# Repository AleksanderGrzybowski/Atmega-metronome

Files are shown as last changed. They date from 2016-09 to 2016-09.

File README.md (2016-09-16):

This is ATmega8 based metronome, useful for my guitar practice. I needed something with wider range of BPM-s, cause my other device only goes down to 40 BPM. Sound is produced from typical 8 Ohm speaker. Board was produced in Merkar (Katowice).
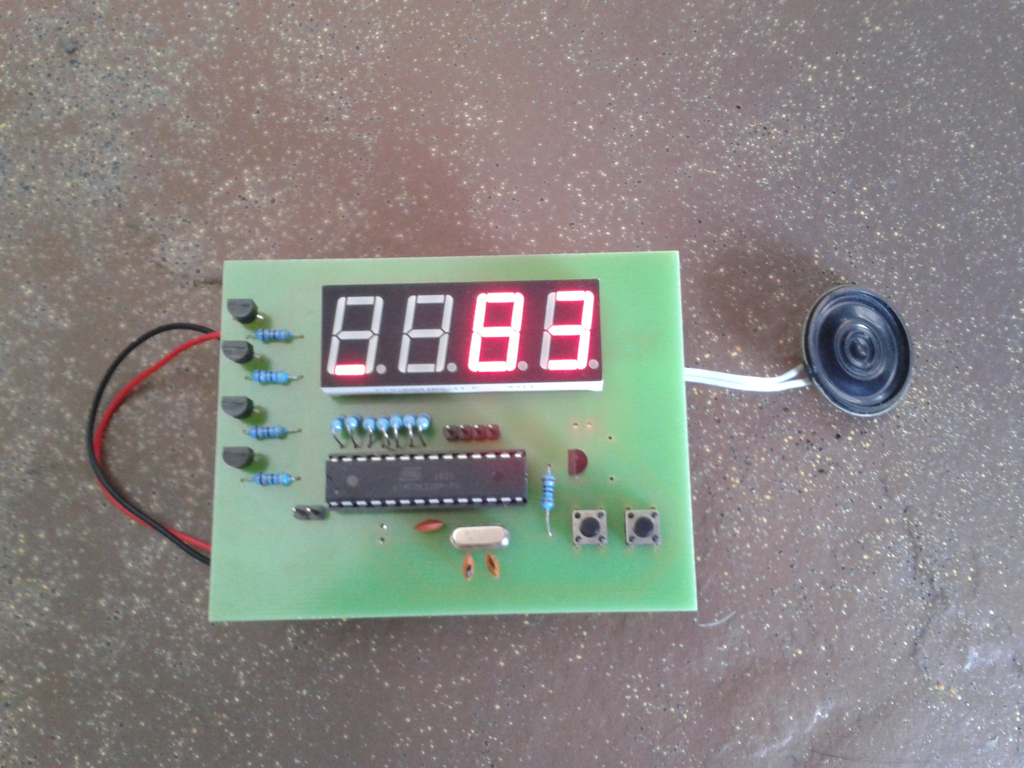
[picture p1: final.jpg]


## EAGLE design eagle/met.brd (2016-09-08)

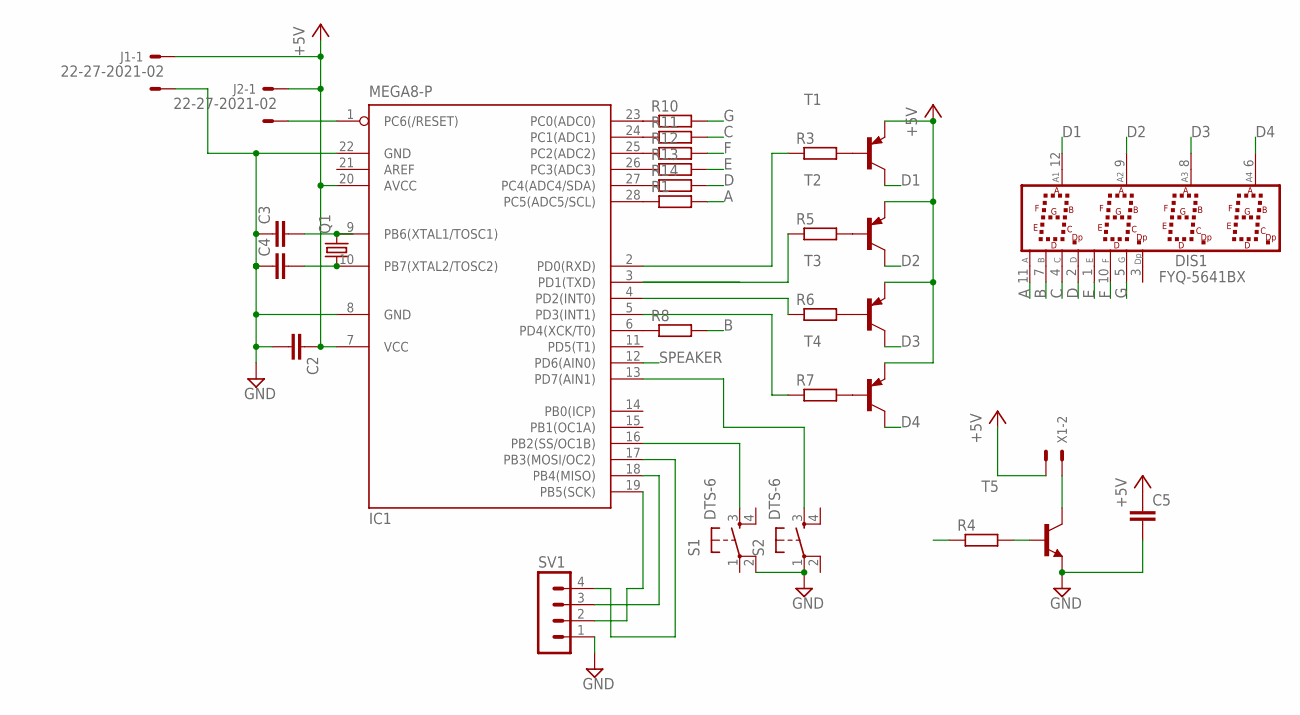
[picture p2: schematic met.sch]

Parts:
C2, C3, C4: C-EU025-024X044; C025-024X044
C5: C-EU075-032X103; C075-032X103
DIS1: FYQ-5641BX; FYQ5641
IC1: MEGA8-P; DIL28-3
J1, J2: 22-27-2021-02; 6410-02
Q1: CRYSTALS-NOGND-HC49; HC49
R1, R8, R10, R11, R12, R13, R14: R-EU_0204/5; 0204/5
R3, R5, R6, R7: R-EU_0207/10; 0207/10
R4: R-EU_0309/12; 0309/12
S1, S2: DTS-6
SV1: MA04-1
T1, T2, T3, T4: BC327-PNP-TO92-EBC; TO92-EBC
T5: BC337-40-NPN-TO92-CBE; TO92-CBE
X1: 22-23-2021

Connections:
+5V: C2.1, C5.1, IC1.7 (VCC), IC1.20 (AVCC), J1.1, T1.E, T2.E, T3.E, T4.E, X1.1
A: DIS1.11 (A), R1.2
B: DIS1.7 (B), R8.2
C: DIS1.4 (C), R11.2
D: DIS1.2 (D), R14.2
D1: DIS1.12 (A1), T1.C
D2: DIS1.9 (A2), T2.C
D3: DIS1.8 (A3), T3.C
D4: DIS1.6 (A4), T4.C
E: DIS1.1 (E), R13.2
F: DIS1.10 (F), R12.2
G: DIS1.5 (G), R10.2
GND: C2.2, C3.1, C4.1, C5.2, IC1.8 (GND), IC1.22 (GND), J1.2, S1.2, S2.1, SV1.1, T5.E
unnamed: C3.2, IC1.9 (PB6(XTAL1/TOSC1)), Q1.2
unnamed: C4.2, IC1.10 (PB7(XTAL2/TOSC2)), Q1.1
unnamed: R3.2, T1.B
unnamed: IC1.1 (PC6(/RESET)), J2.2
unnamed: R5.2, T2.B
unnamed: R6.2, T3.B
unnamed: R7.2, T4.B
unnamed: IC1.2 (PD0(RXD)), R3.1
unnamed: IC1.3 (PD1(TXD)), R5.1
unnamed: IC1.4 (PD2(INT0)), R6.1
unnamed: IC1.5 (PD3(INT1)), R7.1
unnamed: IC1.16 (PB2(SS/OC1B)), S1.3
unnamed: IC1.13 (PD7(AIN1)), S2.3
unnamed: IC1.6 (PD4(XCK/T0)), R8.1
unnamed: IC1.23 (PC0(ADC0)), R10.1
unnamed: IC1.24 (PC1(ADC1)), R11.1
unnamed: IC1.25 (PC2(ADC2)), R12.1
unnamed: IC1.26 (PC3(ADC3)), R13.1
unnamed: IC1.27 (PC4(ADC4/SDA)), R14.1
unnamed: IC1.28 (PC5(ADC5/SCL)), R1.1
unnamed: T5.C, X1.2
unnamed: IC1.19 (PB5(SCK)), SV1.2
unnamed: IC1.18 (PB4(MISO)), SV1.3
unnamed: IC1.17 (PB3(MOSI/OC2)), SV1.4
OFDS: R4.2, T5.B
SPEAKER: IC1.12 (PD6(AIN0)), R4.1

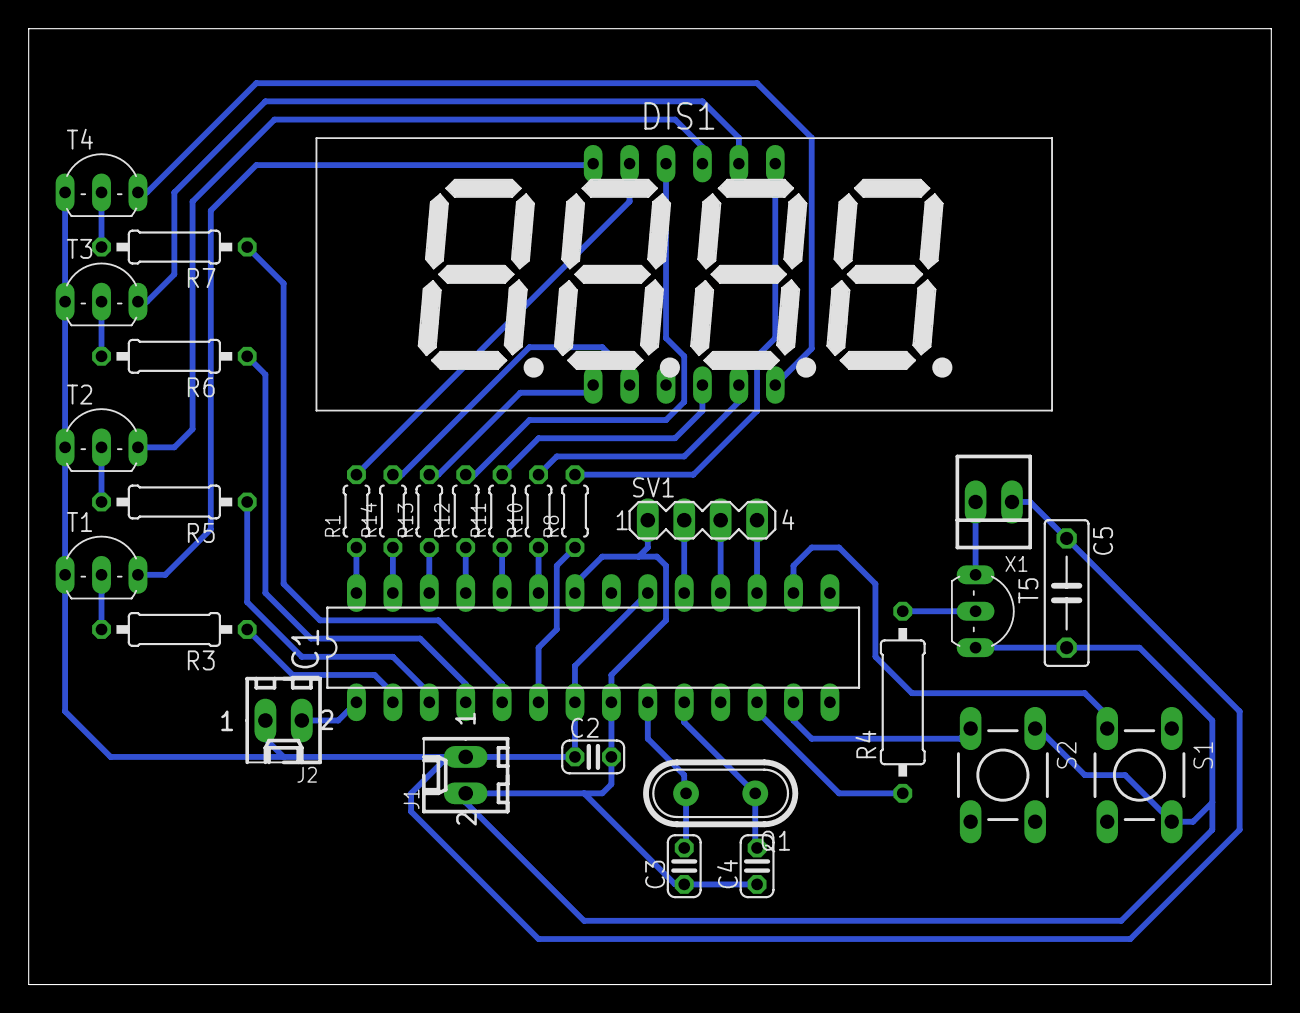
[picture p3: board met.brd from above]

Board: 2 copper layers, 86.7 x 66.7 mm, 30 parts (0 on the bottom side), 39 nets.

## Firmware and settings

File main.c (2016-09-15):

#include <avr/io.h>
#include <util/delay.h>
#include <avr/interrupt.h>
#include <avr/sleep.h>
#include <stdbool.h>

#include "bpm_table.h"

#define B 64
#define A 32
#define D 16
#define E 8
#define F 4
#define C 2
#define G 1


uint8_t digits[12] = { 
    (A + B + C + D + E + F),
    (B + C),
    (A + B + G + E + D),
    (A + B + G + C + D),
    (F + G + B + C),
    (A + F + G + C + D),
    (A + F + G + E + D + C),
    (F + A + B + C),
    (A + B + C + D + E + F + G),
    (A + B + C + D + F + G),
    (0),
    (G)
};

#define EMPTY_DIGIT 10

uint8_t display[4];

void setup_interrupts() {
    // timer 1
    TCCR1B &= ~(1 << CS11);
    TCCR1B |= (1 << CS10) | (1 << CS12);
    TIMSK1 |= (1 << TOIE1);
    TCNT1 = 65530; // some high-ish value
    
    // timer 0
    TCCR0A |= (1 << COM0A1) | (1 << COM0A0) | (1 << WGM00);
    TCCR0B |= (1 << CS00);
    TIMSK0 |= (1 << TOIE0);
    OCR0A = 255; // turned off

    sei();
}


void setup() {
    setup_interrupts();
}

// There was some strange transient that caused a need for this on breadboard,
// not sure if needed now
uint16_t current_bpm = 60 + 1;

bool buzzing = false;
uint8_t buzzing_counter = 0;
#define SOUND_DURATION 10
#define SOUND_PWM_VALUE 128

uint8_t current_digit = 0;


ISR(TIMER0_OVF_vect) {
    if (++current_digit == 4) current_digit = 0;

    // turn off pnp-s to avoid ghosting
    PORTD |= 0b00001111;

    PORTC |= 0b00111111;
    PORTC &= ~(display[current_digit] & 0b00111111);

    // One LCD segment is on PORTD (board routing limitations), so 6-th bit is
    // used for it
    if (display[current_digit] & 0b01000000) { 
        PORTD &= ~(1 << PD4);
    } else {
        PORTD |= (1 << PD4);
    }

    PORTD &= ~(1 << current_digit);

    if (buzzing) {
        OCR0A = SOUND_PWM_VALUE;
        buzzing_counter++;
        if (buzzing_counter > SOUND_DURATION) {
            OCR0A = 255;
            buzzing = false;
            buzzing_counter = 0;
        }
    }
}


uint8_t animation_tab[] = {A, G, D, G}; // top, center, bottom, center, ...
uint8_t animation_index = 0;

ISR(TIMER1_OVF_vect) {
    // array is indexed from 0, so shifting here
    TCNT1 = 65536 - bpm[current_bpm-20];
    buzzing = 1;

    animation_index++;
    if (animation_index >= sizeof(animation_tab)/sizeof(uint8_t)) animation_index = 0;
    display[0] = animation_tab[animation_index];
}

void display_number(uint16_t number) { // 3-digit, first digit is used for animation
    int tmp[3];
    tmp[0] = number % 10;
    number /= 10;
    tmp[1] = number % 10;
    number /= 10;
    tmp[2] = number % 10;

    // remove leading zeros
    int i = 2;
    for (i = 2; i > 0; --i) {
        if (tmp[i] == 0) tmp[i] = EMPTY_DIGIT;
        else break;
    }

    display[1] = digits[tmp[2]];
    display[2] = digits[tmp[1]];
    display[3] = digits[tmp[0]];
}

#define MAX_BPM 200
#define MIN_BPM 20

int main(void) {
    setup();

    DDRC = 0b00111111;
    DDRD = 0b01011111;
    DDRB = 0b00000011;

    // buttons
    PORTD |= (1 << PD7);
    PORTB |= (1 << PB2);

    while(1) {
        if (!(PIND & (1 << PD7)) && current_bpm > MIN_BPM) {
            current_bpm--;
        }
        if (!(PINB & (1 << PB2)) && current_bpm < MAX_BPM) {
            current_bpm++;
        }
        display_number(current_bpm);
        _delay_ms(50);
    }
}

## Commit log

2016-08-18 Working TIMER1
2016-08-18 Working both timers
2016-08-18 Working buttons
2016-08-18 Cleanup, remove ghosting 'fix'
    [main.c]
2016-09-08 Shuffle IO around to match the board
2016-09-08 Fix refactoring error, faster rolling
    [main.c]
2016-09-08 Eagle schematic and board
    [met.brd, met.sch]
